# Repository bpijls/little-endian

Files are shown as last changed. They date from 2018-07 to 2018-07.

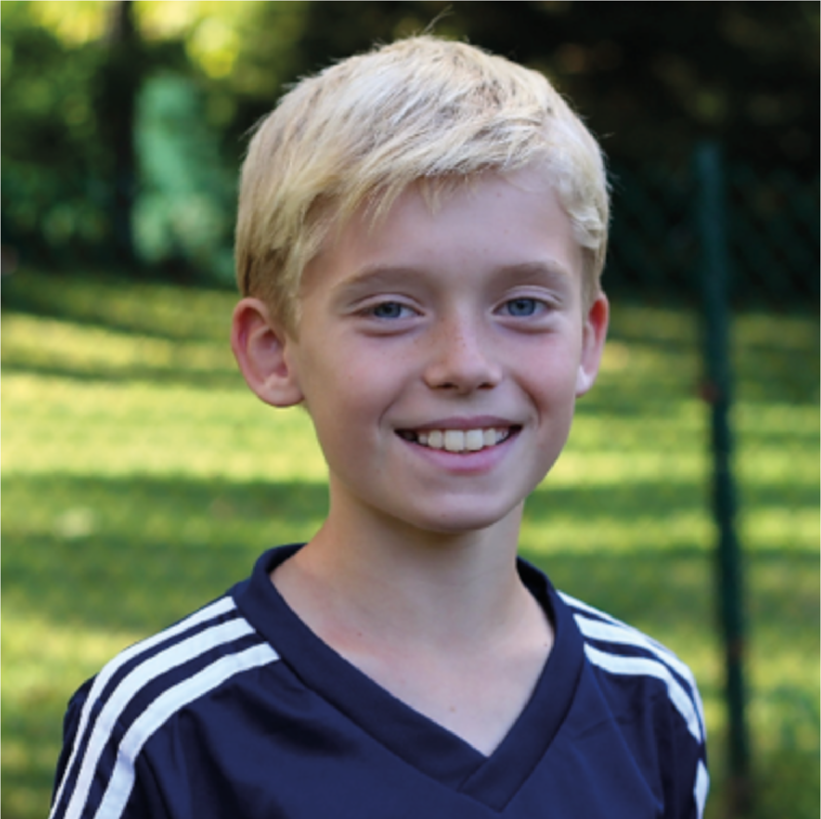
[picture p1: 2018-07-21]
src/react-application/src/img/profile.png

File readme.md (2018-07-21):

#Readme

Little-Endian is a little rover-like robot to be used for educational purposes, created by students from the Amsterdam University of Applied Sciences, (HBO-ICT, Minor IoT). The robot itself is based on a WiFi enabled microcontroller (the ESP8266) and can be programmed with a web-based blockly programming environment. For more detailed information, refer to the [design documentation](https://github.com/bpijls/little-endian/tree/master/documentation). 

**Building the robot**
The robot frame can be lasercut from 3mm mdf 
[PCB](https://dirtypcbs.com/store/designer/details/23296/6093/little-endian)

**Installation**

*	Install 'docker' and 'docker-compose' on your webserver
*	Clone this repository to a folder
*	Rename env.example to .env and determine the host name and virtual host subdomains
*	Run 'docker-compose build' from the root folder of this repository
*	To run the server, run 'docker-compose up' from the root folder
*	the server can be reached using the virtual host names you determined in the .env file or by typing the IP addres of the server in the address bar of your webbrowser. The webapplications runs on port 3000 and the socket server runs on port 8000.

**Usage**

Log in to the webapplication by entering a robot-id

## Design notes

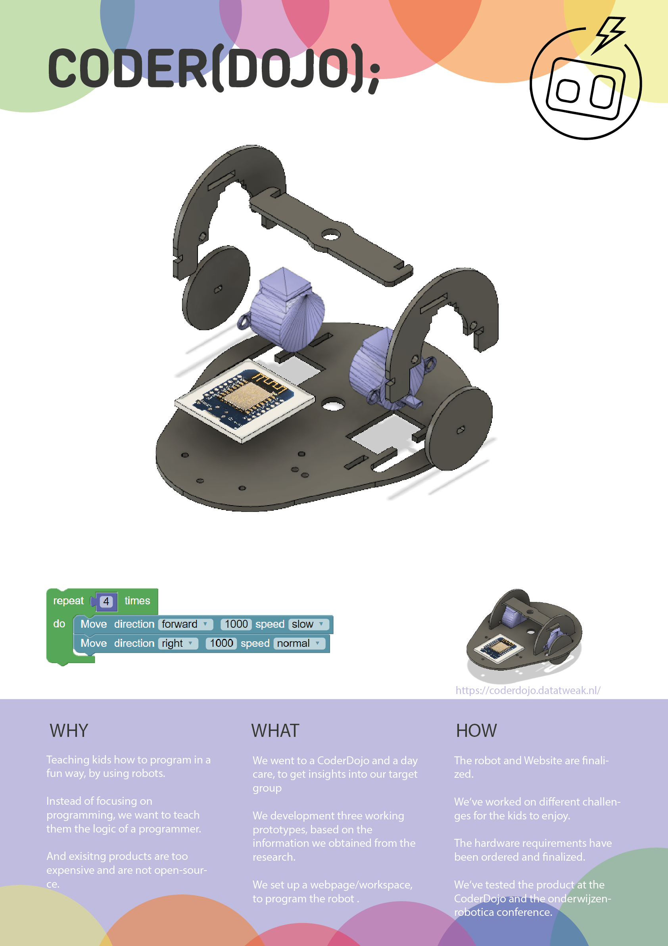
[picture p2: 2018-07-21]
documentation/little-endian-poster-final.png

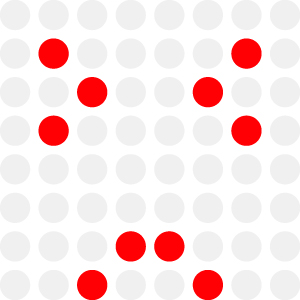
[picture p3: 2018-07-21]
src/react-application/src/img/emotions/disgust.jpg

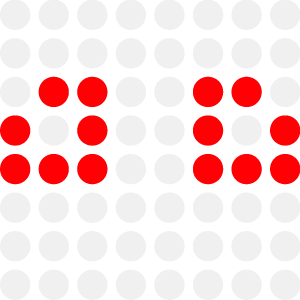
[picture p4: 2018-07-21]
src/react-application/src/img/emotions/sadness.png

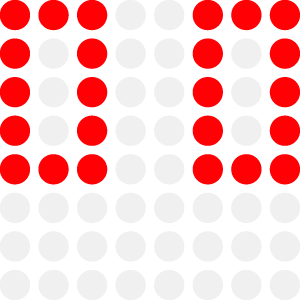
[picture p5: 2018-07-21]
src/react-application/src/img/emotions/surprise.png

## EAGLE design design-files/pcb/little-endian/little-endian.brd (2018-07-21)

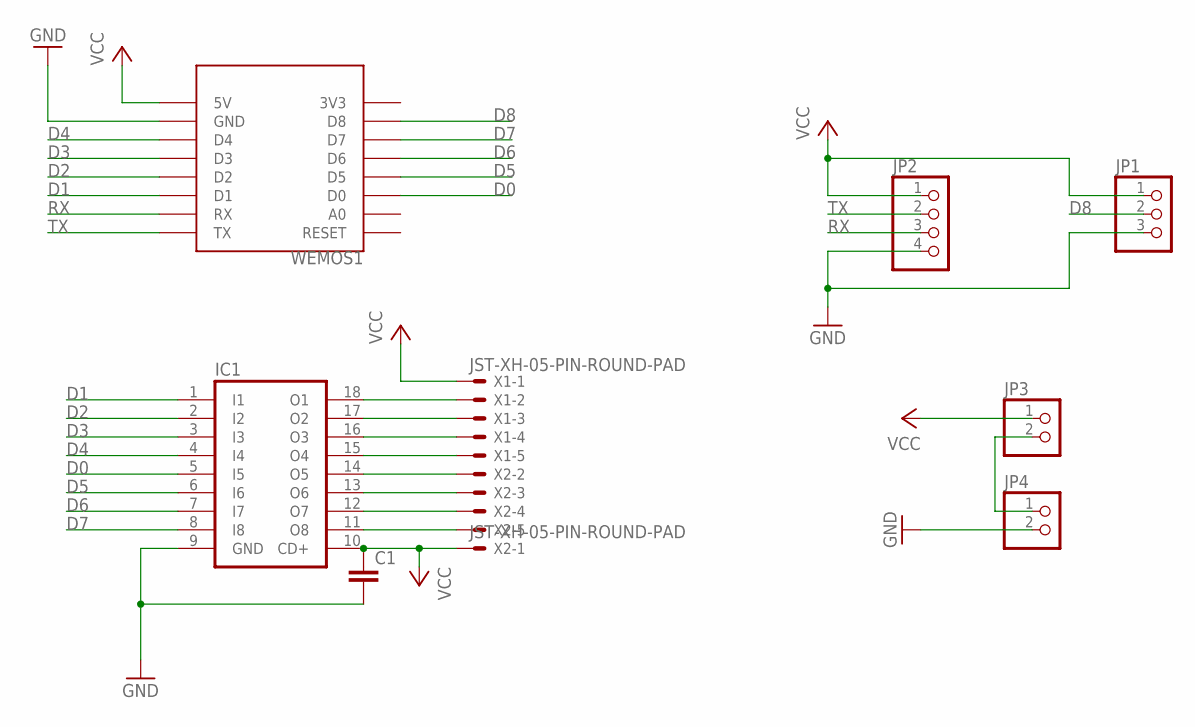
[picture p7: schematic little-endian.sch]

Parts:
C1: C-EU050-030X075; C050-030X075
IC1: ULN2803A; DIL18
JP1: PINHD-1X3; 1X03
JP2: PINHD-1X4; 1X04
JP3, JP4: PINHD-1X2; 1X02
WEMOS1: WEMOS-D1-MINI
X1, X2: JST-XH-05-PIN-ROUND-PAD; JST-XH-05-PACKAGE-ROUND-PAD

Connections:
D0: IC1.5 (I5), WEMOS1.D0
D1: IC1.1 (I1), WEMOS1.D1
D2: IC1.2 (I2), WEMOS1.D2
D3: IC1.3 (I3), WEMOS1.D3
D4: IC1.4 (I4), WEMOS1.D4
D5: IC1.6 (I6), WEMOS1.D5
D6: IC1.7 (I7), WEMOS1.D6
D7: IC1.8 (I8), WEMOS1.D7
D8: JP1.2, WEMOS1.D8
GND: C1.2, IC1.9 (GND), JP1.3, JP2.4, JP4.2, WEMOS1.GND
unnamed: JP3.2, JP4.1
unnamed: IC1.11 (O8), X2.5
unnamed: IC1.12 (O7), X2.4
unnamed: IC1.13 (O6), X2.3
unnamed: IC1.14 (O5), X2.2
unnamed: IC1.15 (O4), X1.5
unnamed: IC1.16 (O3), X1.4
unnamed: IC1.17 (O2), X1.3
unnamed: IC1.18 (O1), X1.2
RX: JP2.3, WEMOS1.RX
TX: JP2.2, WEMOS1.TX
VCC: C1.1, IC1.10 (CD+), JP1.1, JP2.1, JP3.1, WEMOS1.5V, X1.1, X2.1

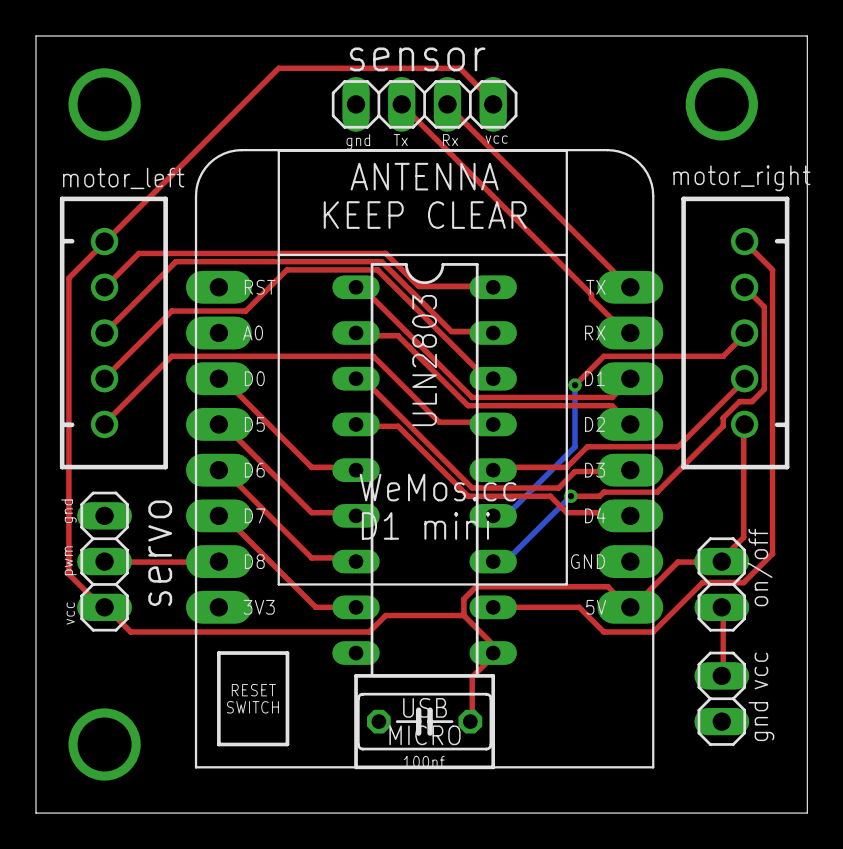
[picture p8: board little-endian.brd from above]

Board: 2 copper layers, 42.9 x 43.2 mm, 9 parts (0 on the bottom side), 22 nets.

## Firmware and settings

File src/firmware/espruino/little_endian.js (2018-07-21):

/* Copyright (c) 2017 Gordon Williams, Pur3 Ltd. See the file LICENSE for copying permission. */
function StepperMotor(obj) {
  this.pins = obj.pins;
  this.pattern = obj.pattern || [0b0010,0b0001,0b0100,0b1000];
  this.offpattern = obj.offpattern || 0;
  this.pos = 0;
  this.stepsPerSec = obj.stepsPerSec || 300;
  this.onstep = obj.onstep || 0;
}

StepperMotor.prototype.setHome = function() {
  this.pos = 0;
};

StepperMotor.prototype.getPosition = function() {
  return this.pos;
};

StepperMotor.prototype.stop = function(turnOff) {
  if (this.interval) {
    clearInterval(this.interval);
    this.interval = undefined;
  }
  if (turnOff)
    digitalWrite(this.pins, this.offpattern);
};

StepperMotor.prototype.moveTo = function(pos, milliseconds, callback, turnOff) {
  pos = 0|pos;
  if (milliseconds===undefined)
    milliseconds = Math.abs(pos-this.pos)*1000/this.stepsPerSec;
  this.stop(turnOff);
  if (pos != this.pos) {
    var stepper = this;
    var step = function() {
      if (stepper.pos == pos) {
        stepper.stop(turnOff);
        if (callback)
          callback();
      } else {
        stepper.pos += (pos < stepper.pos) ? -1 : 1;
        digitalWrite(stepper.pins, stepper.pattern[ stepper.pos & (stepper.pattern.length-1) ]);
      }
      if (stepper.onstep) stepper.onstep(stepper.pos);
    };
    this.interval = setInterval(step, milliseconds / Math.abs(pos-this.pos));
    step();
  } else {
    if (callback)
      setTimeout(callback, milliseconds);
  }
};

var motorLeft = new StepperMotor({
  pins:[D0,D2,D4,D5]
});

var motorRight = new StepperMotor({
  pins:[D12,D13,D14,D16]
});

var queue = [];

function forward(steps) {
  print("forward");
  motorRight.moveTo(motorRight.getPosition()+steps, undefined, callNextFunction);
  motorLeft.moveTo(motorLeft.getPosition()-steps);
}


function backward(steps) {
  print("backwards");
  motorRight.moveTo(motorRight.getPosition()-steps, undefined, callNextFunction);
  motorLeft.moveTo(motorLeft.getPosition()+steps);
}


function turnRight(steps) {
  print("turnRight");
  motorRight.moveTo(motorRight.getPosition()-steps, undefined, callNextFunction);
  motorLeft.moveTo(motorLeft.getPosition()-steps);
}

function turnLeft(steps) {
  print("turnLeft");
  motorRight.moveTo(motorRight.getPosition()+steps, undefined, callNextFunction);
  motorLeft.moveTo(motorLeft.getPosition()+steps);
}

function turn(direction, degrees){
  var d = degrees * 14;
  if(direction == 'turnRight'){
    queue.push('turnRight('+d+')');
  }
  else{
    queue.push('turnLeft('+d+')');
  }
}

function move(direction, steps){
  if(direction == 'forward'){
    queue.push('forward('+steps+')');
  }
  else if(direction == 'backward'){
    queue.push('backward('+steps+')');
  }
}

function callNextFunction(){
  if(queue.length > 0){
    eval(queue[0]);
    queue.shift();
  }
}

/* embed websocket module here */
/** Minify String.fromCharCode() call */
var strChr = String.fromCharCode;

function buildKey() {
  var randomString = btoa(Math.random().toString(36).substr(2, 18));
  var toHash = randomString + '258EAFA5-E914-47DA-95CA-C5AB0DC85B11';
  return {
    source: randomString,
    hashed: btoa(require('crypto').SHA1(toHash))
  }
}

function WebSocket(host, options) {
  this.socket = null;
  options = options || {};
  this.host = host;
  this.port = options.port || 80;
  this.protocolVersion = options.protocolVersion || 13;
  this.origin = options.origin || 'Espruino';
  this.keepAlive = options.keepAlive * 1000 || 60000;
  this.masking = options.masking!==undefined ? options.masking : true;
  this.path = options.path || "/";
  this.protocol = options.protocol;
  this.lastData = "";
  this.key = buildKey();
  this.connected = false || options.connected;
  this.headers = options.headers || {};
}

WebSocket.prototype.initializeConnection = function () {
  require("net").connect({
    host: this.host,
    port: this.port
  }, this.onConnect.bind(this));
};

WebSocket.prototype.onConnect = function (socket) {
  this.socket = socket;
  var ws = this;
  socket.on('data', this.parseData.bind(this));
  socket.on('close', function () {
    if (ws.pingTimer) {
      clearInterval(ws.pingTimer);
      ws.pingTimer = undefined;
    }
    ws.emit('close');
  });

  this.handshake();
};

WebSocket.prototype.parseData = function (data) {
  // see https://developer.mozilla.org/en-US/docs/Web/API/WebSockets_API/Writing_WebSocket_servers
  // Note, docs specify bits 0-7, etc - but BIT 0 is the MSB, 7 is the LSB
  var ws = this;
  this.emit('rawData', data);

  if (this.lastData.length) {
    data = this.lastData+data;
    this.lastData="";
  }

  if (!this.connected) {
    // FIXME - not a good idea!
    if (data.indexOf(this.key.hashed) > -1 && data.indexOf('\r\n\r\n') > -1) {
      this.emit('handshake');
      this.pingTimer = setInterval(function () {
        ws.send('ping', 0x89);
      }, this.keepAlive);
      data = data.substring(data.indexOf('\r\n\r\n') + 4);
      this.connected = true;
      this.emit('open');
    }
    this.lastData = data;
    return;
  }

  while (data.length) {
    var offset = 2;
    var opcode = data.charCodeAt(0)&15;
    var dataLen = data.charCodeAt(1)&127;
    if (dataLen==126) {
      dataLen = data.charCodeAt(3) | (data.charCodeAt(2)<<8);
      offset += 2;
    } else if (dataLen==127) throw "Messages >65535 in length unsupported";
    var pktLen = dataLen+offset+((data.charCodeAt(1)&128)?4/*mask*/:0);
    if (pktLen > data.length) {
      // we received the start of a packet, but not enough of it for a full message.
      // store it for later, so when we get the next packet we can do the whole message
      this.lastData = data;
      return;
    }

    switch (opcode) {
      case 0xA:
      this.emit('pong');
      break;
      case 0x9:
      this.send('pong', 0x8A);
      this.emit('ping');
      break;
      case 0x8:
      this.socket.end();
      break;
      case 0:
      case 1:
      var mask = [ 0,0,0,0 ];
      if (data.charCodeAt(1)&128 /* mask */)
        mask = [ data.charCodeAt(offset++), data.charCodeAt(offset++),
      data.charCodeAt(offset++), data.charCodeAt(offset++)];
      var msg = "";
      for (var i = 0; i < dataLen; i++)
        msg += String.fromCharCode(data.charCodeAt(offset++) ^ mask[i&3]);
      this.emit('message', msg);
      break;
      default:
      console.log("WS: Unknown opcode "+opcode);
    }
    data = data.substr(pktLen);
  }
};
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
